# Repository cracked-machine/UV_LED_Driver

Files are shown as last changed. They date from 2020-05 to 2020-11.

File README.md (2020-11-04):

# UV LightBox

- Required Kicad Hardware library: https://github.com/cracked-machine/KicadLibrary
- Related SW project: https://github.com/cracked-machine/UV_LED_Driver_SW_STM32F051

This is a modular design that drives 4 panels of UV LEDS and 1 standard LED string.

<P>


</P>

- When the lightbox lid is open the standard LEDS are enabled. Their brightness can be adjusted using the rotary encoder control.
- When the lightbox lid is closed the UV LEDS are enabled.
- A timer will keep the UV LEDS enabled. When the timeout expires a buzzer will sound and the UV LEDS will be disabled. The timeout can be adjusted when using two buttons in steps of 10 seconds.
- A QVGA (2.2" 320x240) TFT LCD display shows the timer value.

- **OOTB operation runs on 5VDC. However, if higher voltage is required regulators U2 and U4 can be populated. These protect the LCD and Buzzer (JP3 and JP1 must be ON, JP2 and JP4 must be OFF)**

Module |Front |Back
:-----:|:-----:|:-----:
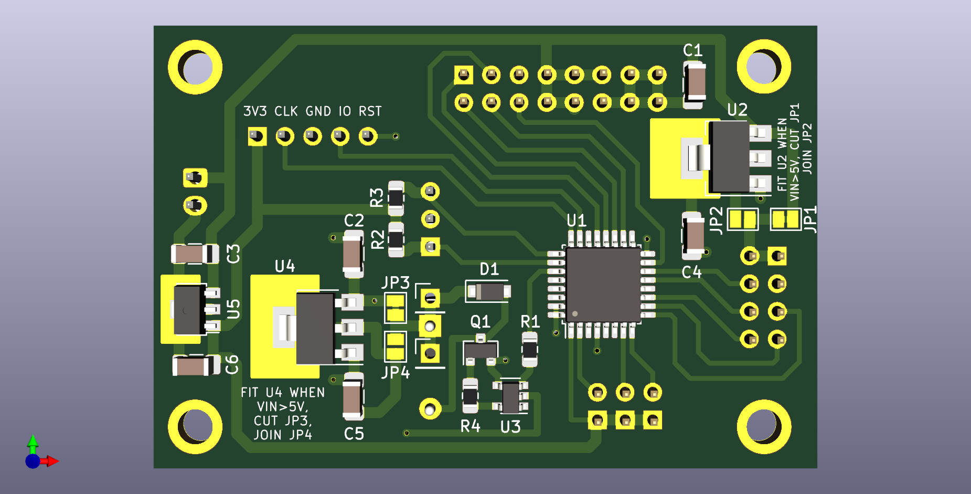
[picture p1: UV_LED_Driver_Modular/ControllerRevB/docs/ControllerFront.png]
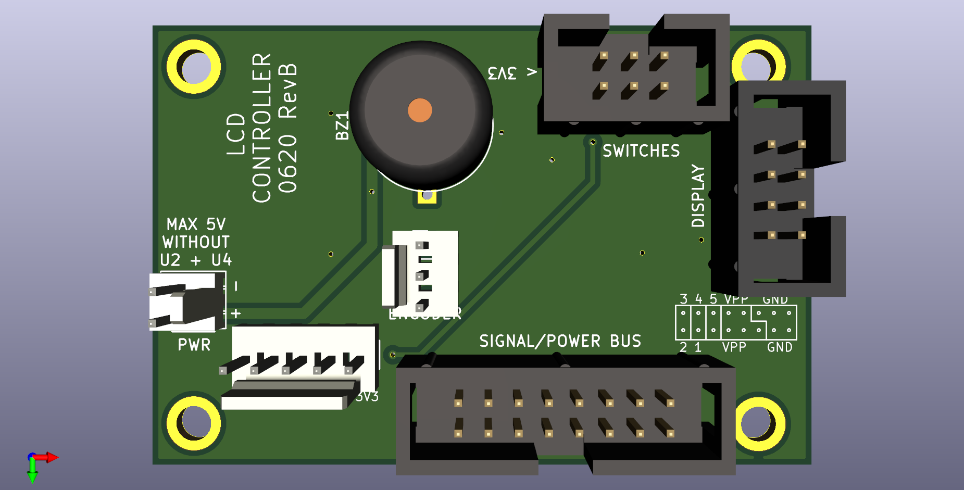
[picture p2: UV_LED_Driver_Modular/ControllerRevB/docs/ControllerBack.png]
Controller||
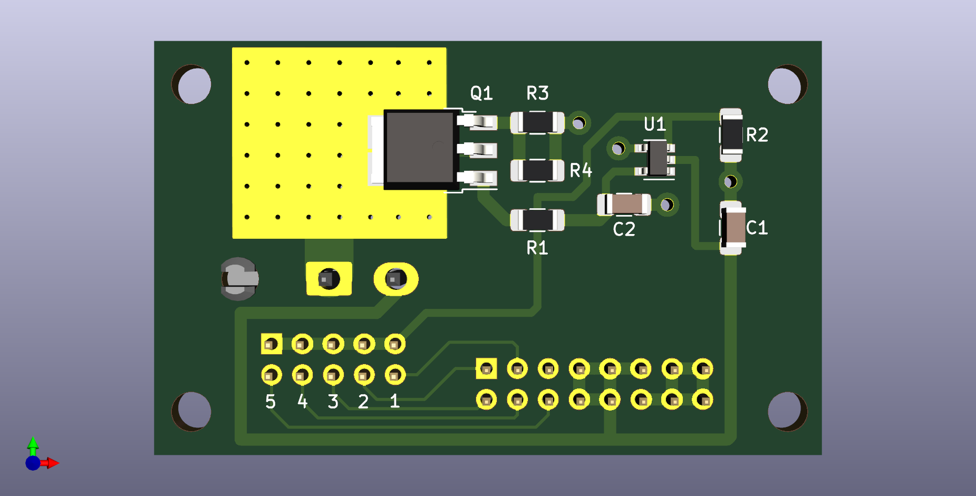
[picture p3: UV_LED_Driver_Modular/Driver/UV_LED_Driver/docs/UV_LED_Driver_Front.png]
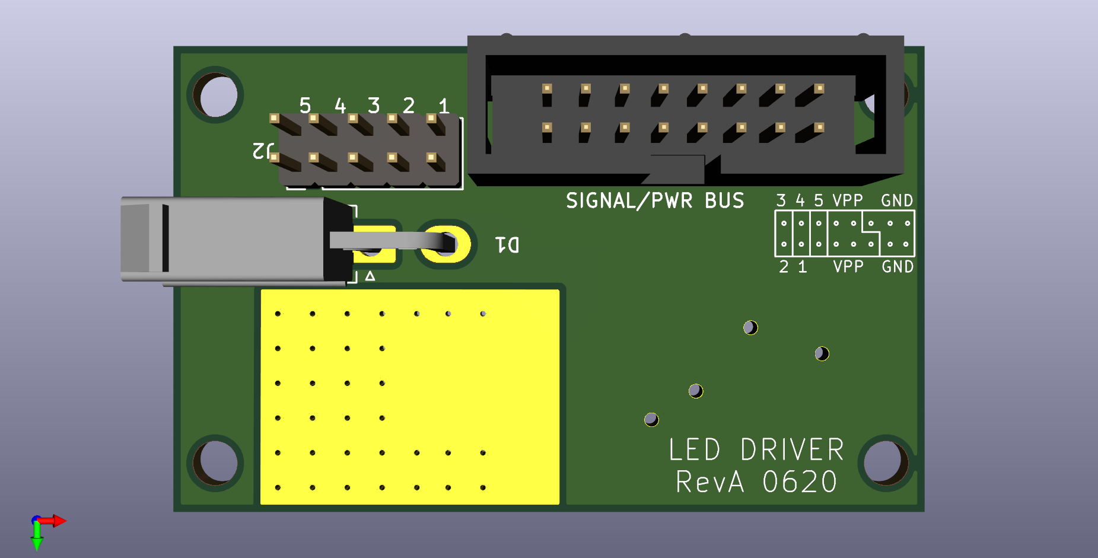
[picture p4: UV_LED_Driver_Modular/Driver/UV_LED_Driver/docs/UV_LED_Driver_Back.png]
Driver||

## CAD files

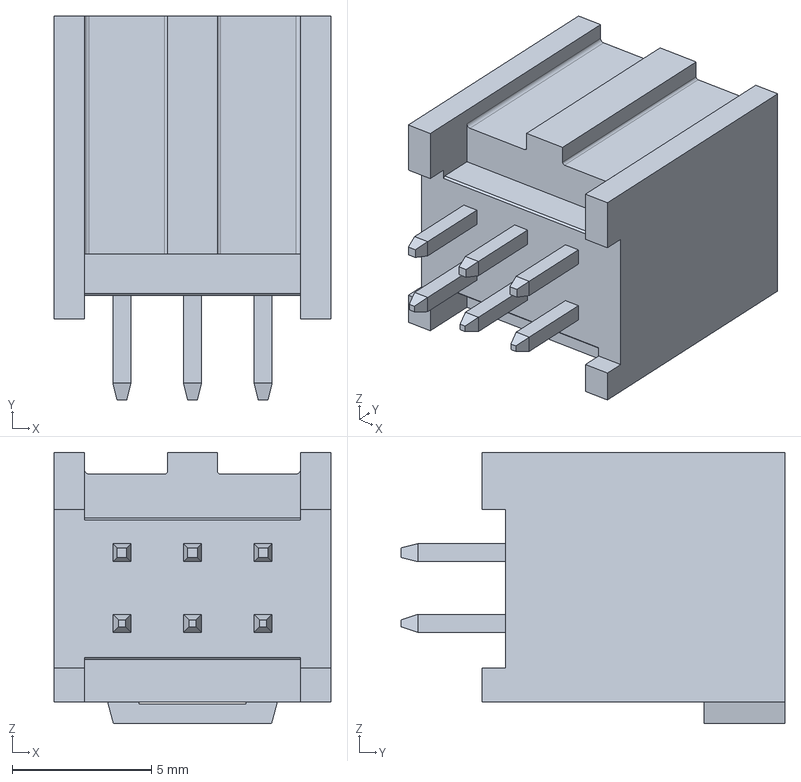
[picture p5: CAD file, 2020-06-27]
UV_LED_Driver_Modular/ControllerRevB/step/Molex_C-Grid_III_90130_6_Way_2_Row_Straight_PCB_Header_901301206.stp
9.96 x 13.8 x 9.75 mm

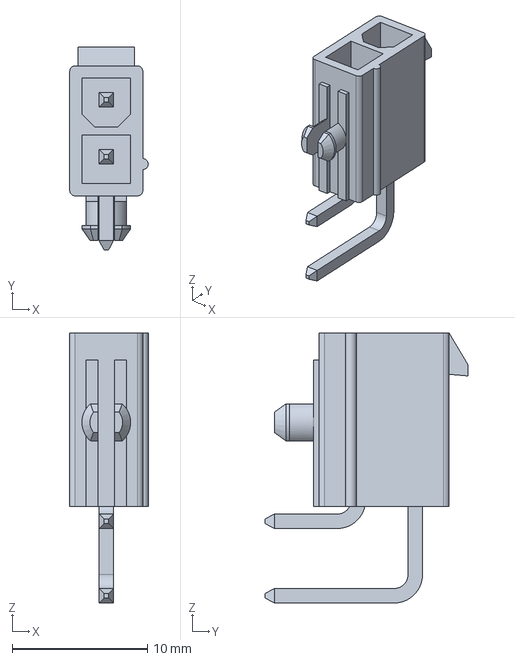
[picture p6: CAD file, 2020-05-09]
UV_LED_Driver_Modular/Driver/UV_LED_Driver/3D/39301020.stp
5.80 x 15.0 x 19.9 mm

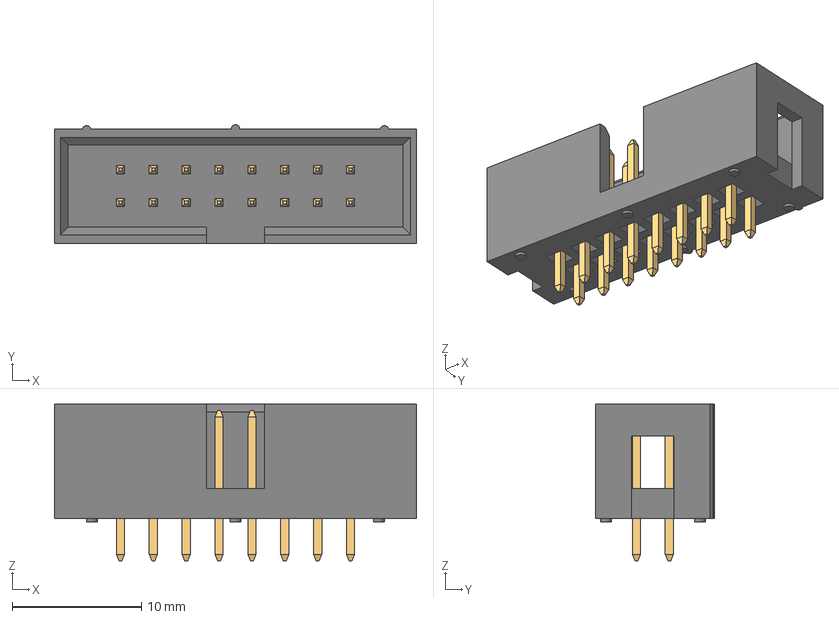
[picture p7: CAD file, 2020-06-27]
UV_LED_Driver_Modular/ControllerRevB/step/61201621621_Download_STP_61201621621_rev1.stp
28.0 x 9.18 x 12.1 mm
6120xx21621_PIN x 16

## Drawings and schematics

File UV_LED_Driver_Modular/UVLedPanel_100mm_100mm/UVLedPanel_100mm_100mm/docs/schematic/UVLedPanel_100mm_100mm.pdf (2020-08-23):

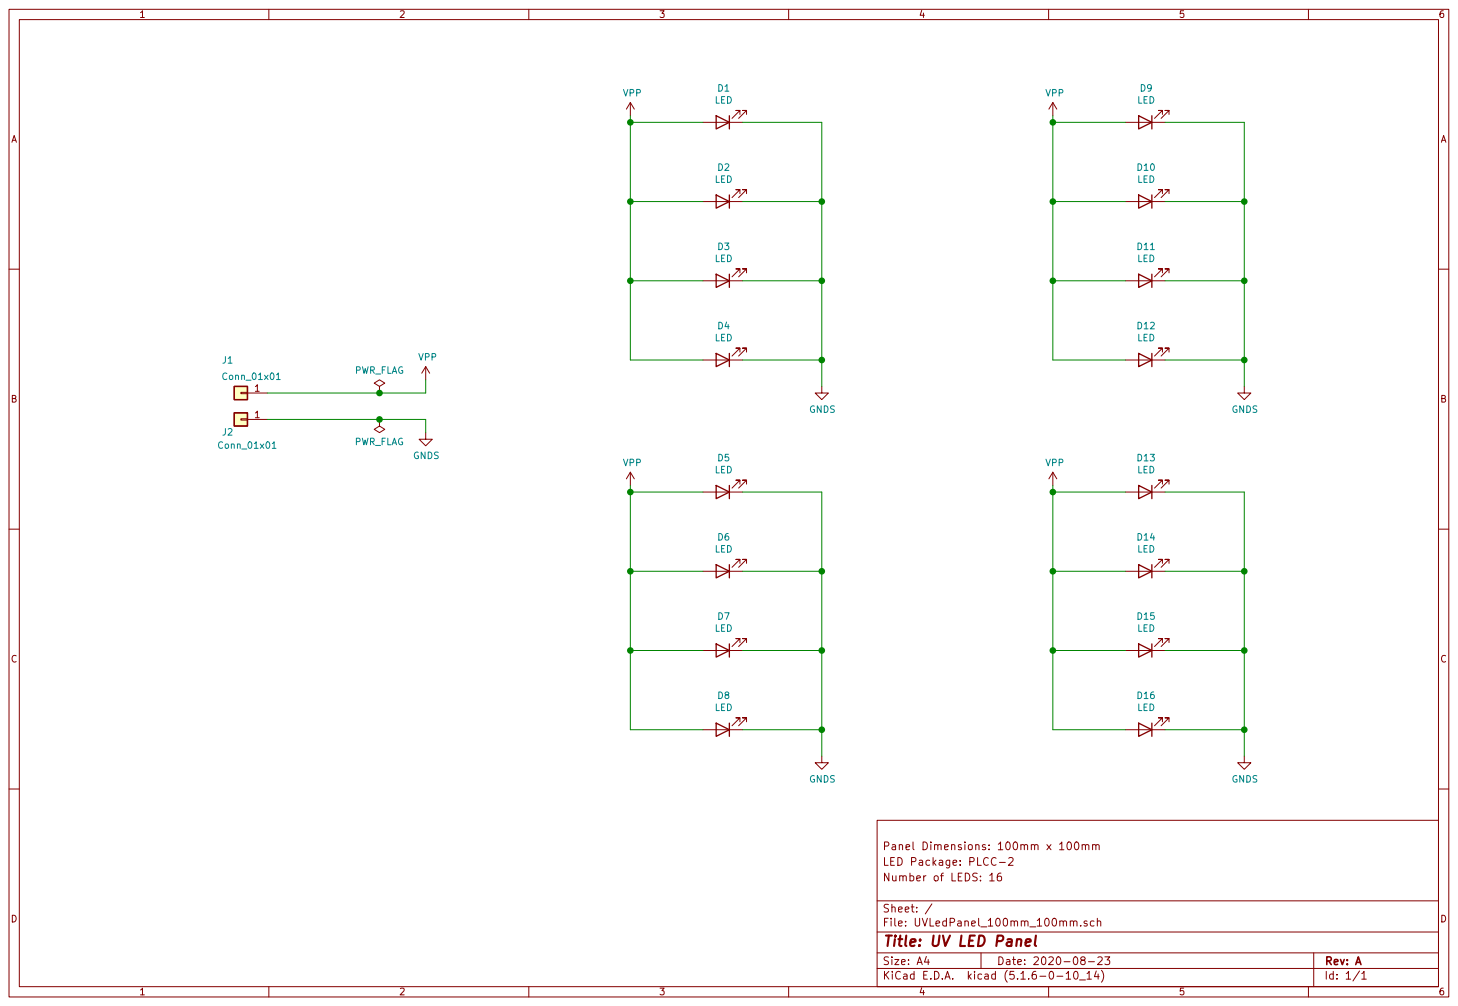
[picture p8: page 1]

LED Package: PLCC-2 Panel Dimensions: 100mm x 100mm

File: UVLedPanel_100mm_100mm.sch Sheet: / Number of LEDS: 16

Id: 1/1 Title: UV LED Panel

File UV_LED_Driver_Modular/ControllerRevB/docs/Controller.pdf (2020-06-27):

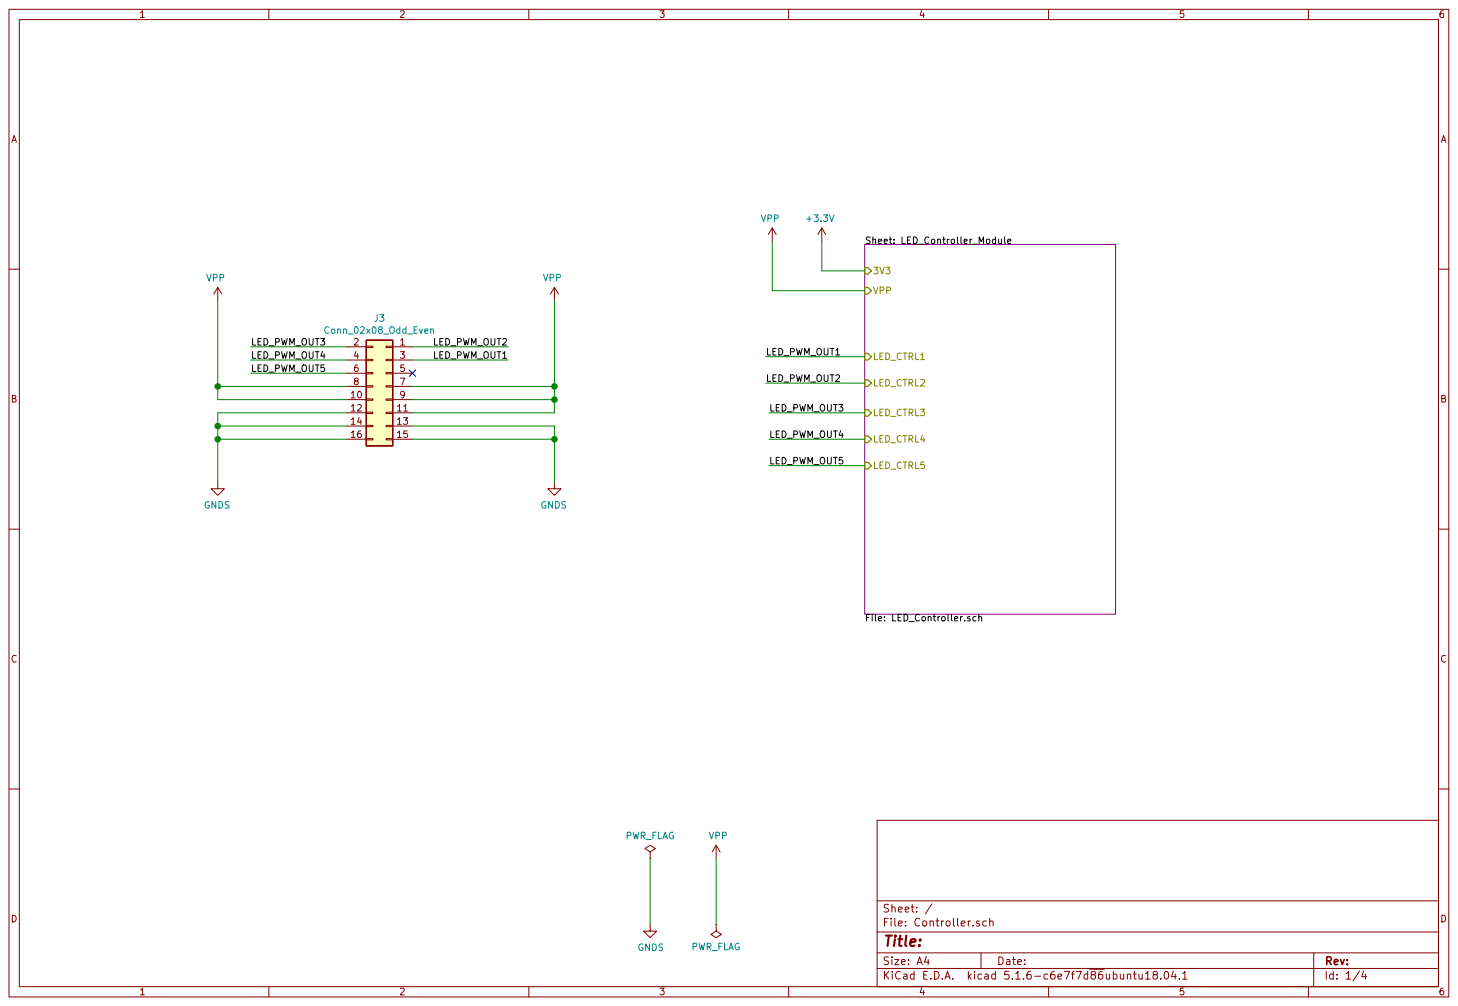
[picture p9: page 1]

14 | 13
16 | 15

Id: 1/4 Title: File: Controller.sch Sheet: /

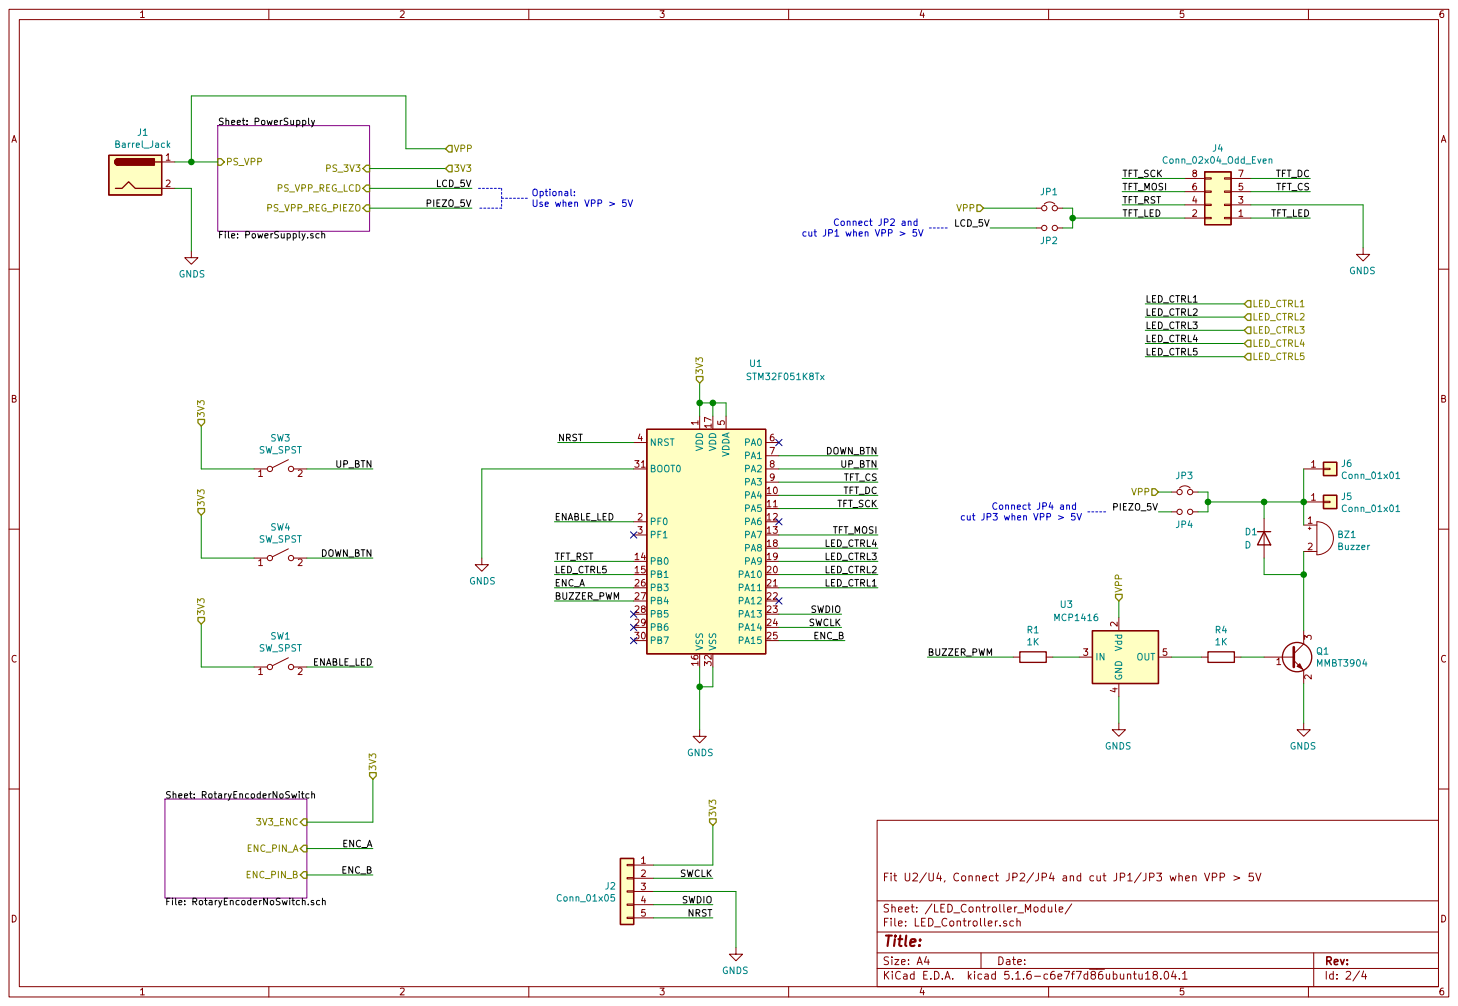
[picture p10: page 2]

Fit U2/U4, Connect JP2/JP4 and cut JP1/JP3 when VPP > 5V

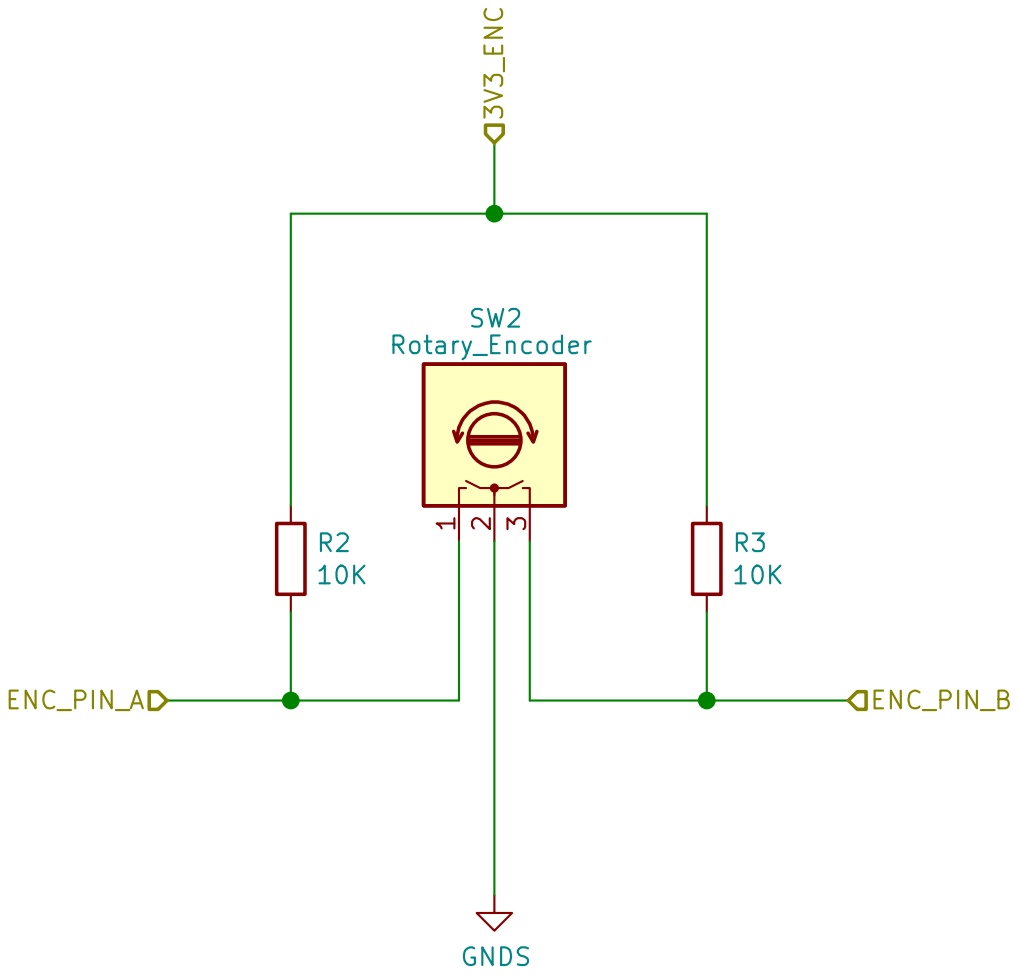
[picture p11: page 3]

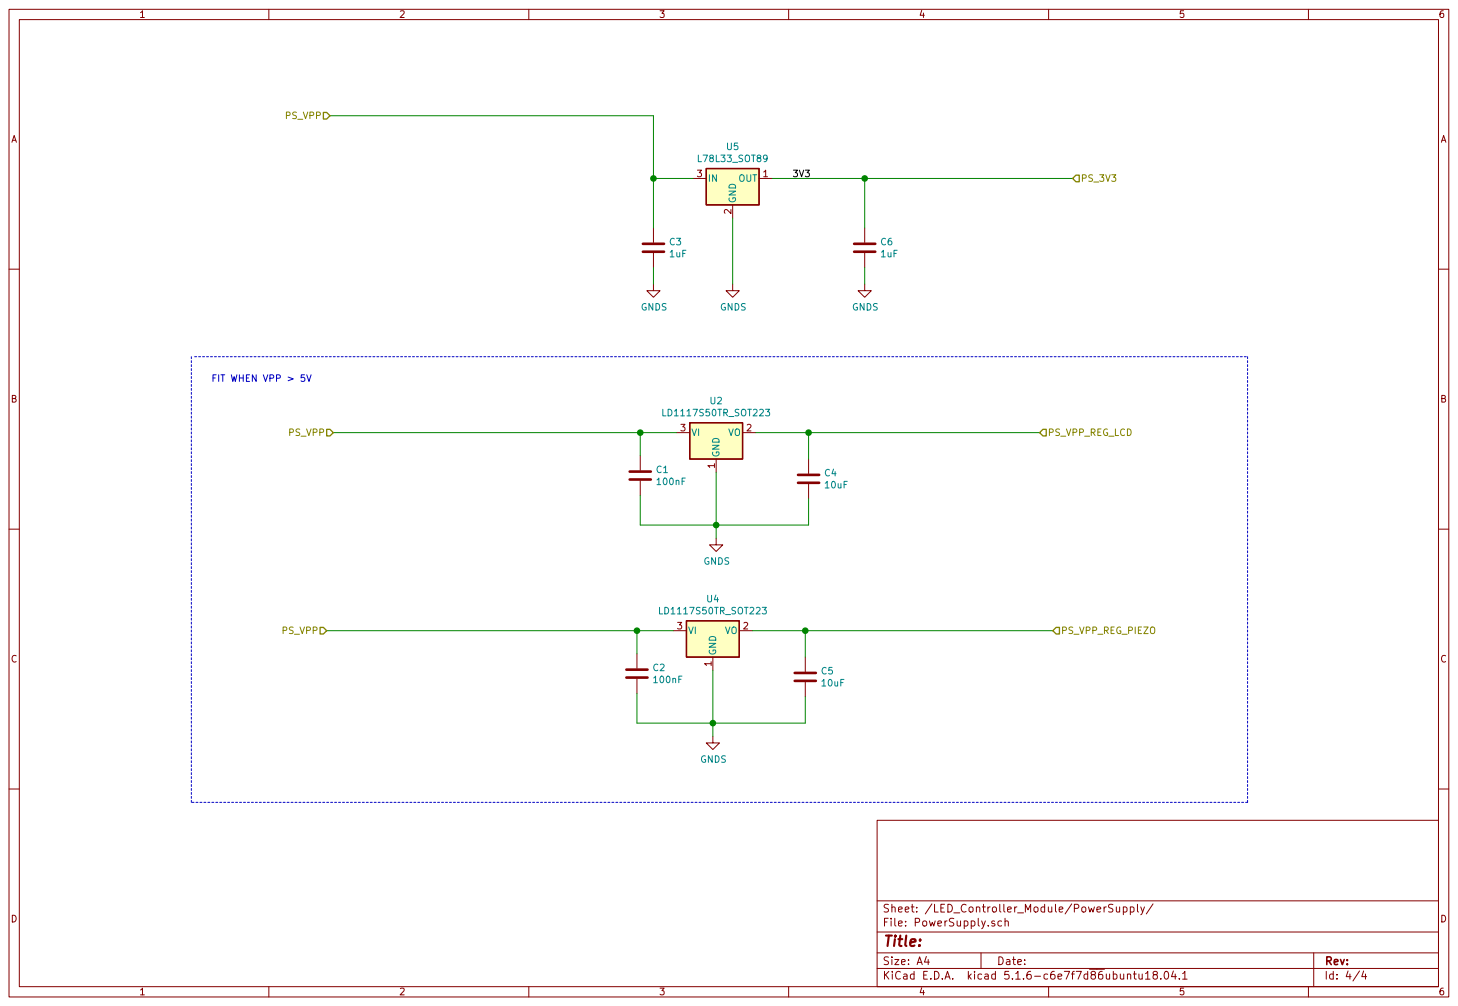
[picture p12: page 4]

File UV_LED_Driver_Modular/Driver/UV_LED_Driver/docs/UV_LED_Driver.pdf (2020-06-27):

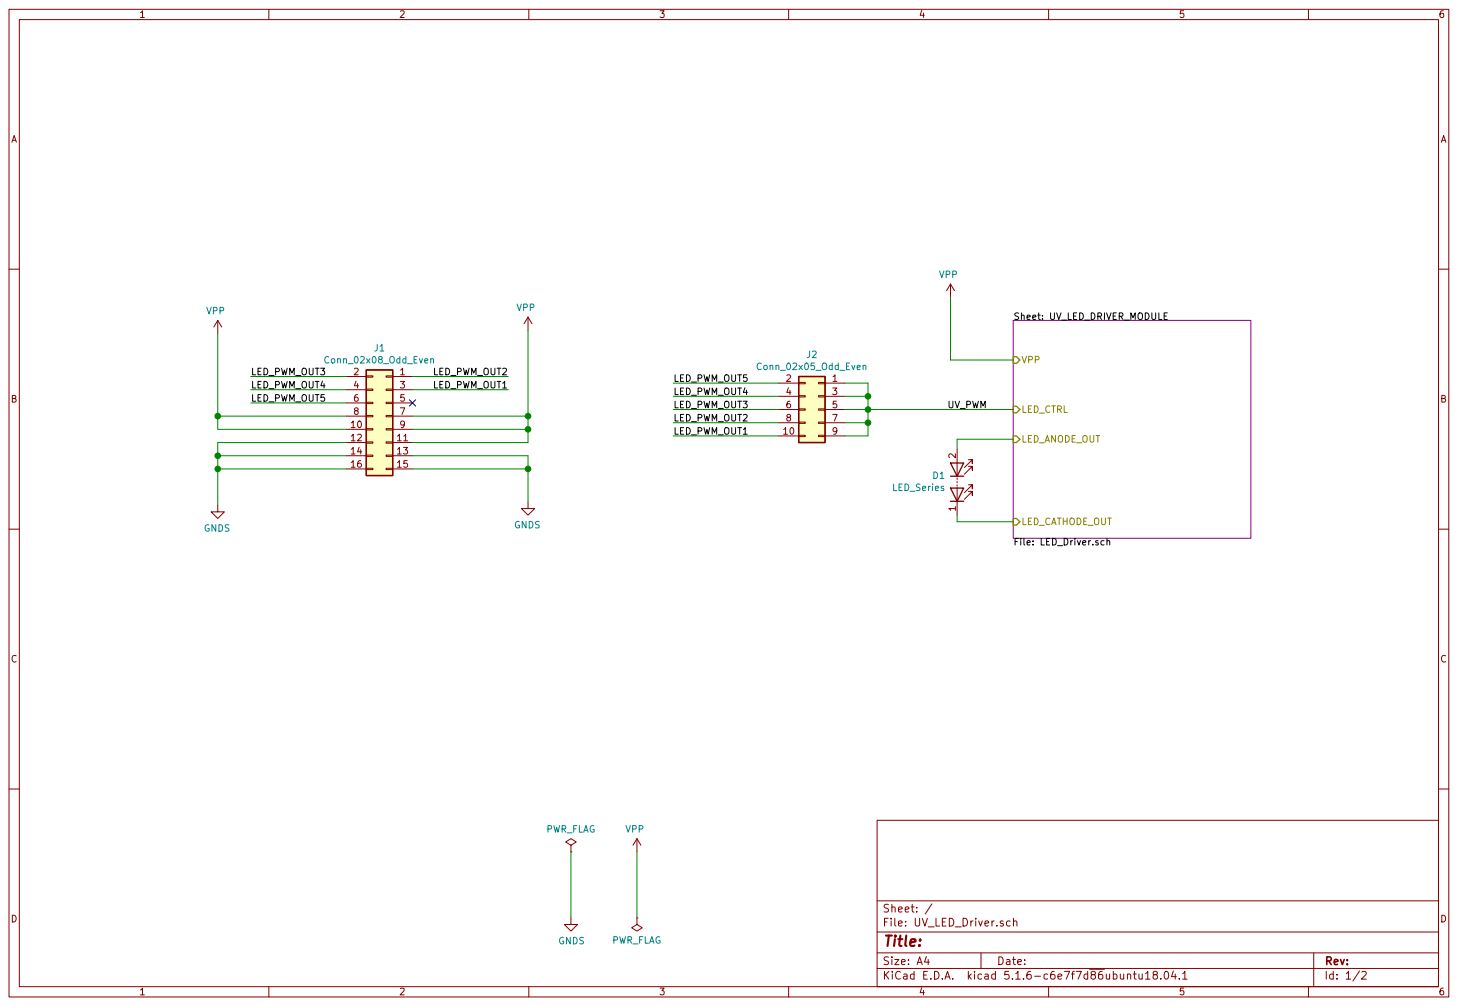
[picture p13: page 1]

14 | 13
16 | 15

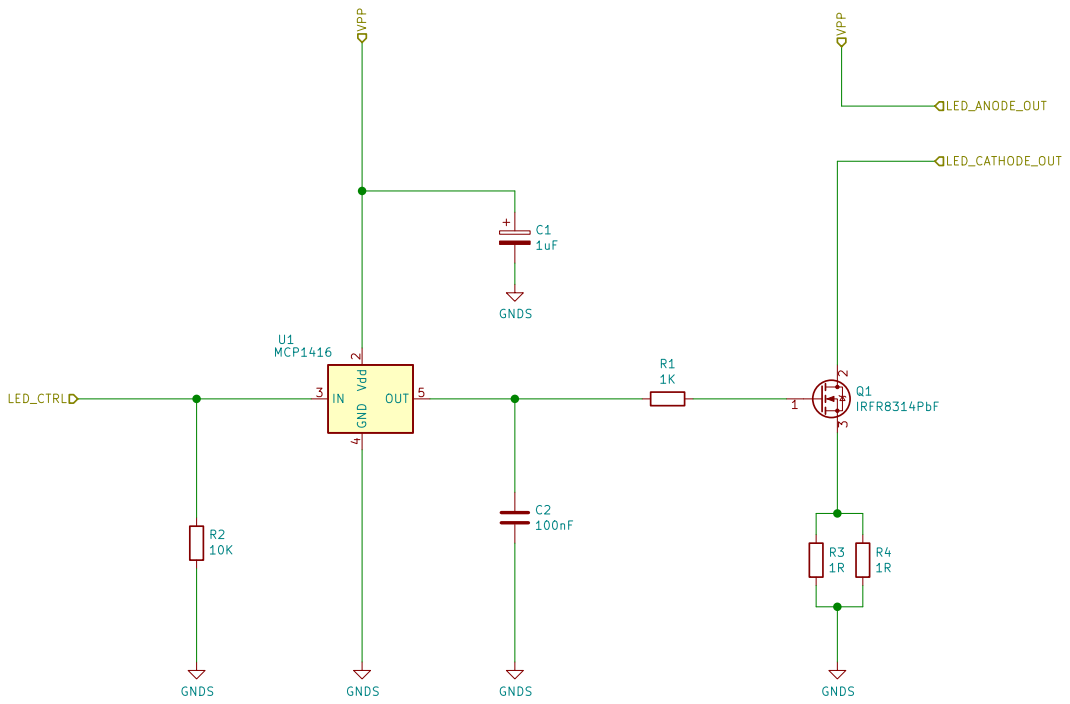
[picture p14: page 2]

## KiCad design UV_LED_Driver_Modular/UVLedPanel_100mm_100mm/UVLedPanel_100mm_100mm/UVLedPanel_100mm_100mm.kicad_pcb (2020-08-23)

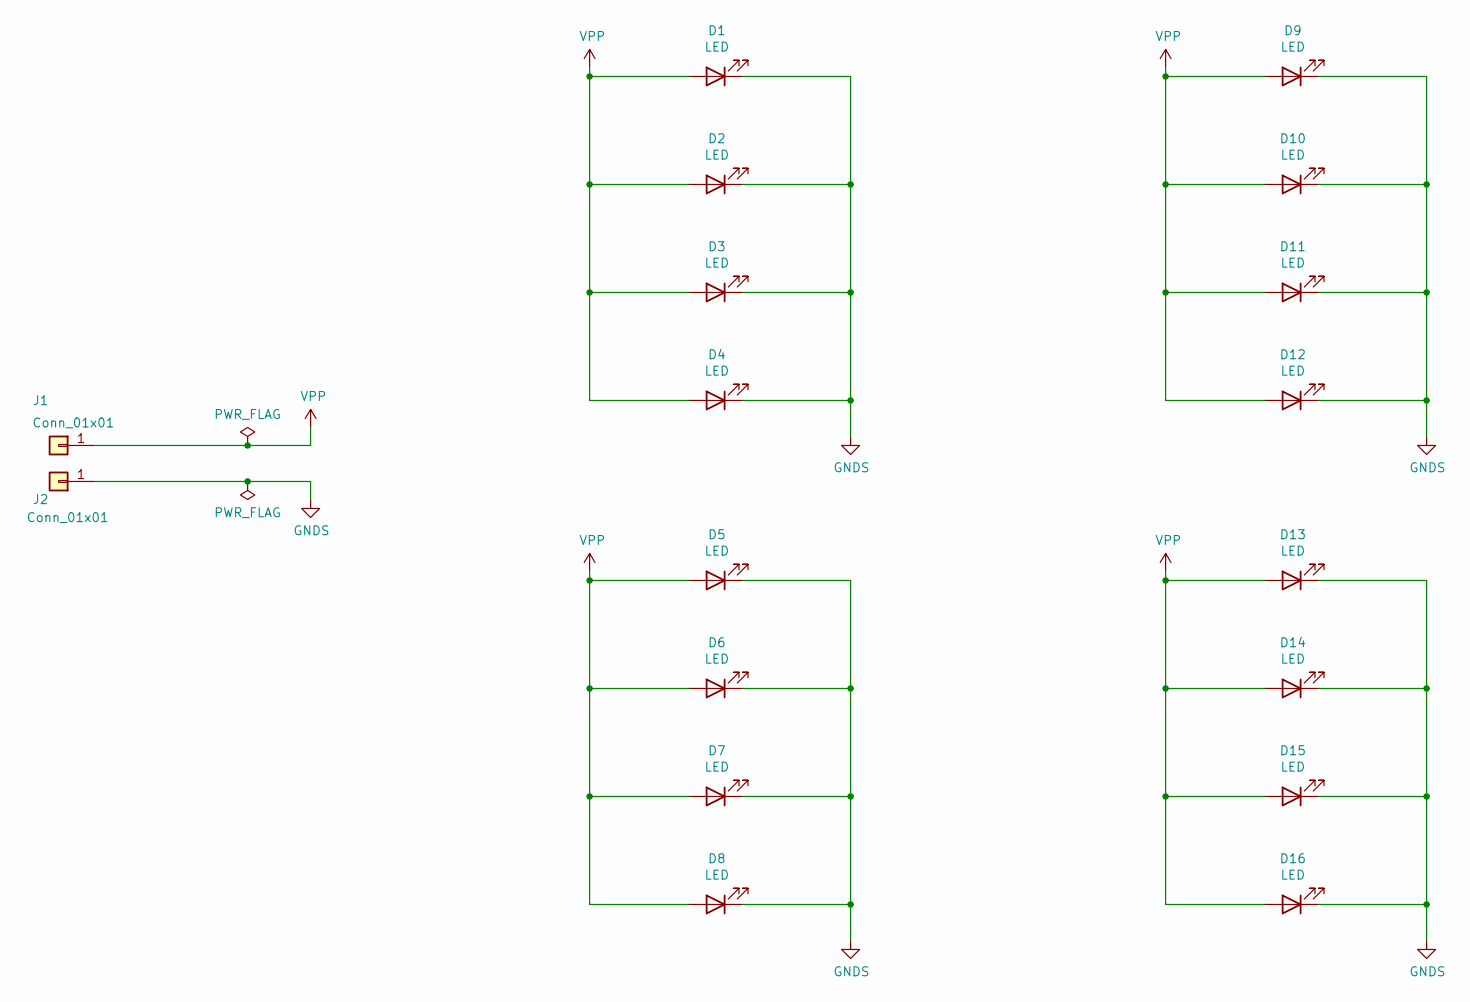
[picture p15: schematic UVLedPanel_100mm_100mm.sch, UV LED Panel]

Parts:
D1, D2, D3, D4, D5, D6, D7, D8, D9, D10, D11, D12, D13, D14, D15, D16: LED; LED_PLCC-2
J1, J2: Conn_01x01; TestPoint_Pad_4.0x4.0mm

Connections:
GNDS: D1.1 (K), D2.1 (K), D3.1 (K), D4.1 (K), D5.1 (K), D6.1 (K), D7.1 (K), D8.1 (K), D9.1 (K), D10.1 (K), D11.1 (K), D12.1 (K), D13.1 (K), D14.1 (K), D15.1 (K), D16.1 (K), J2.1
VPP: D1.2 (A), D2.2 (A), D3.2 (A), D4.2 (A), D5.2 (A), D6.2 (A), D7.2 (A), D8.2 (A), D9.2 (A), D10.2 (A), D11.2 (A), D12.2 (A), D13.2 (A), D14.2 (A), D15.2 (A), D16.2 (A), J1.1

Board: 2 copper layers, 18 parts (0 on the bottom side), 2 nets, no tracks yet.

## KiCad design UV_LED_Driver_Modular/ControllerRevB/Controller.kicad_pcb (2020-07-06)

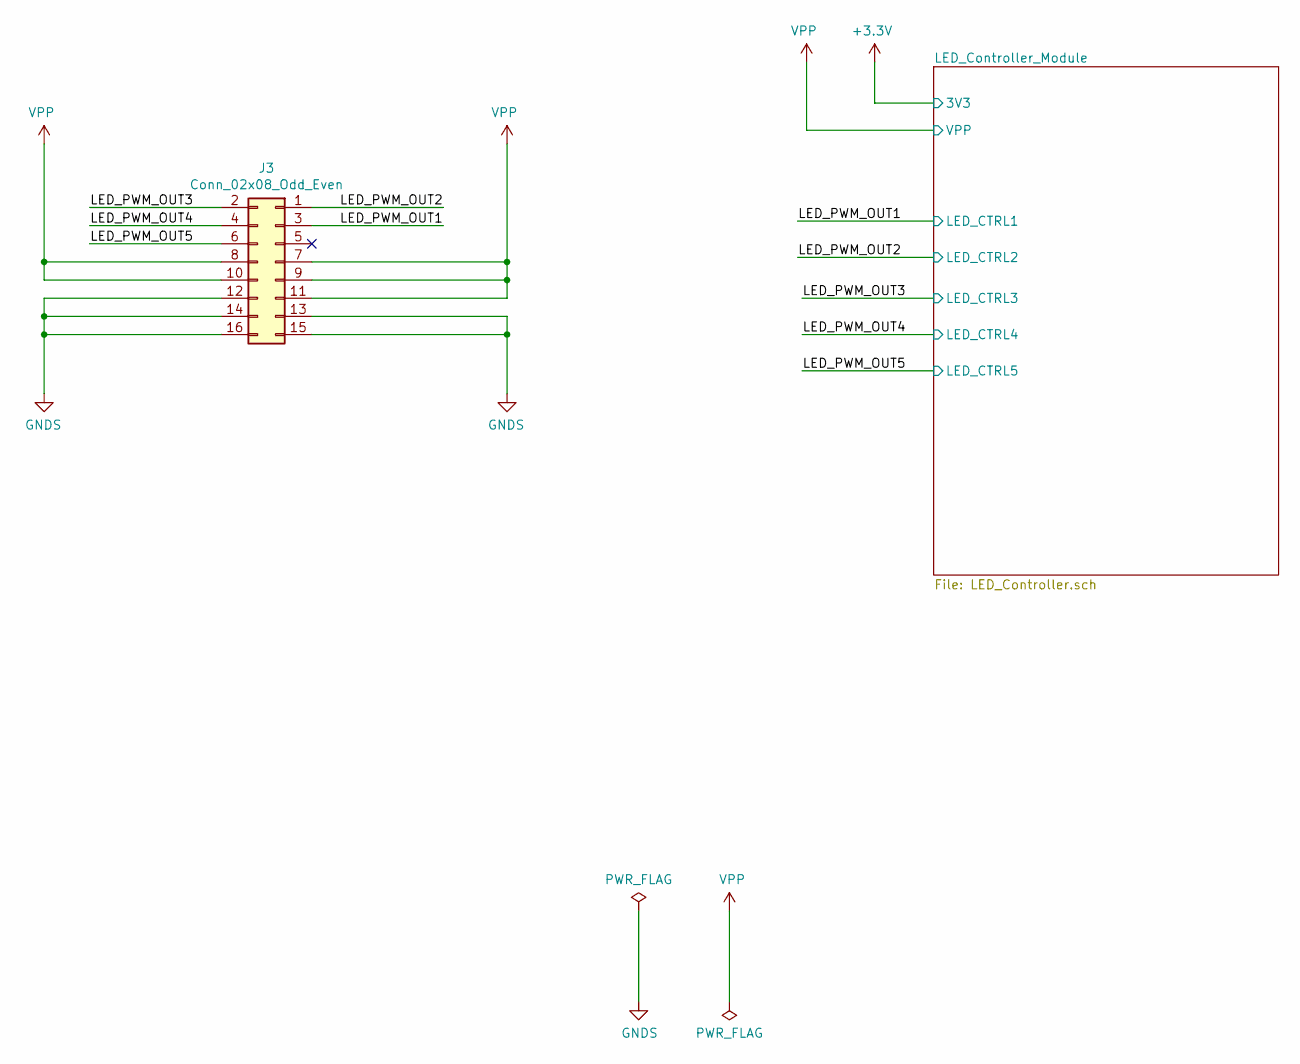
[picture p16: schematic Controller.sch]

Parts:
J3: Conn_02x08_Odd_Even; PinHeader_2x08_P2.54mm_Vertical

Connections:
/LED_PWM_OUT1: J3.3; also elsewhere on the board
/LED_PWM_OUT2: J3.1; also elsewhere on the board
/LED_PWM_OUT3: J3.2; also elsewhere on the board
/LED_PWM_OUT4: J3.4; also elsewhere on the board
/LED_PWM_OUT5: J3.6; also elsewhere on the board
GNDS: J3.12, J3.13, J3.14, J3.15, J3.16; also elsewhere on the board
VPP: J3.7, J3.8, J3.9, J3.10, J3.11; also elsewhere on the board

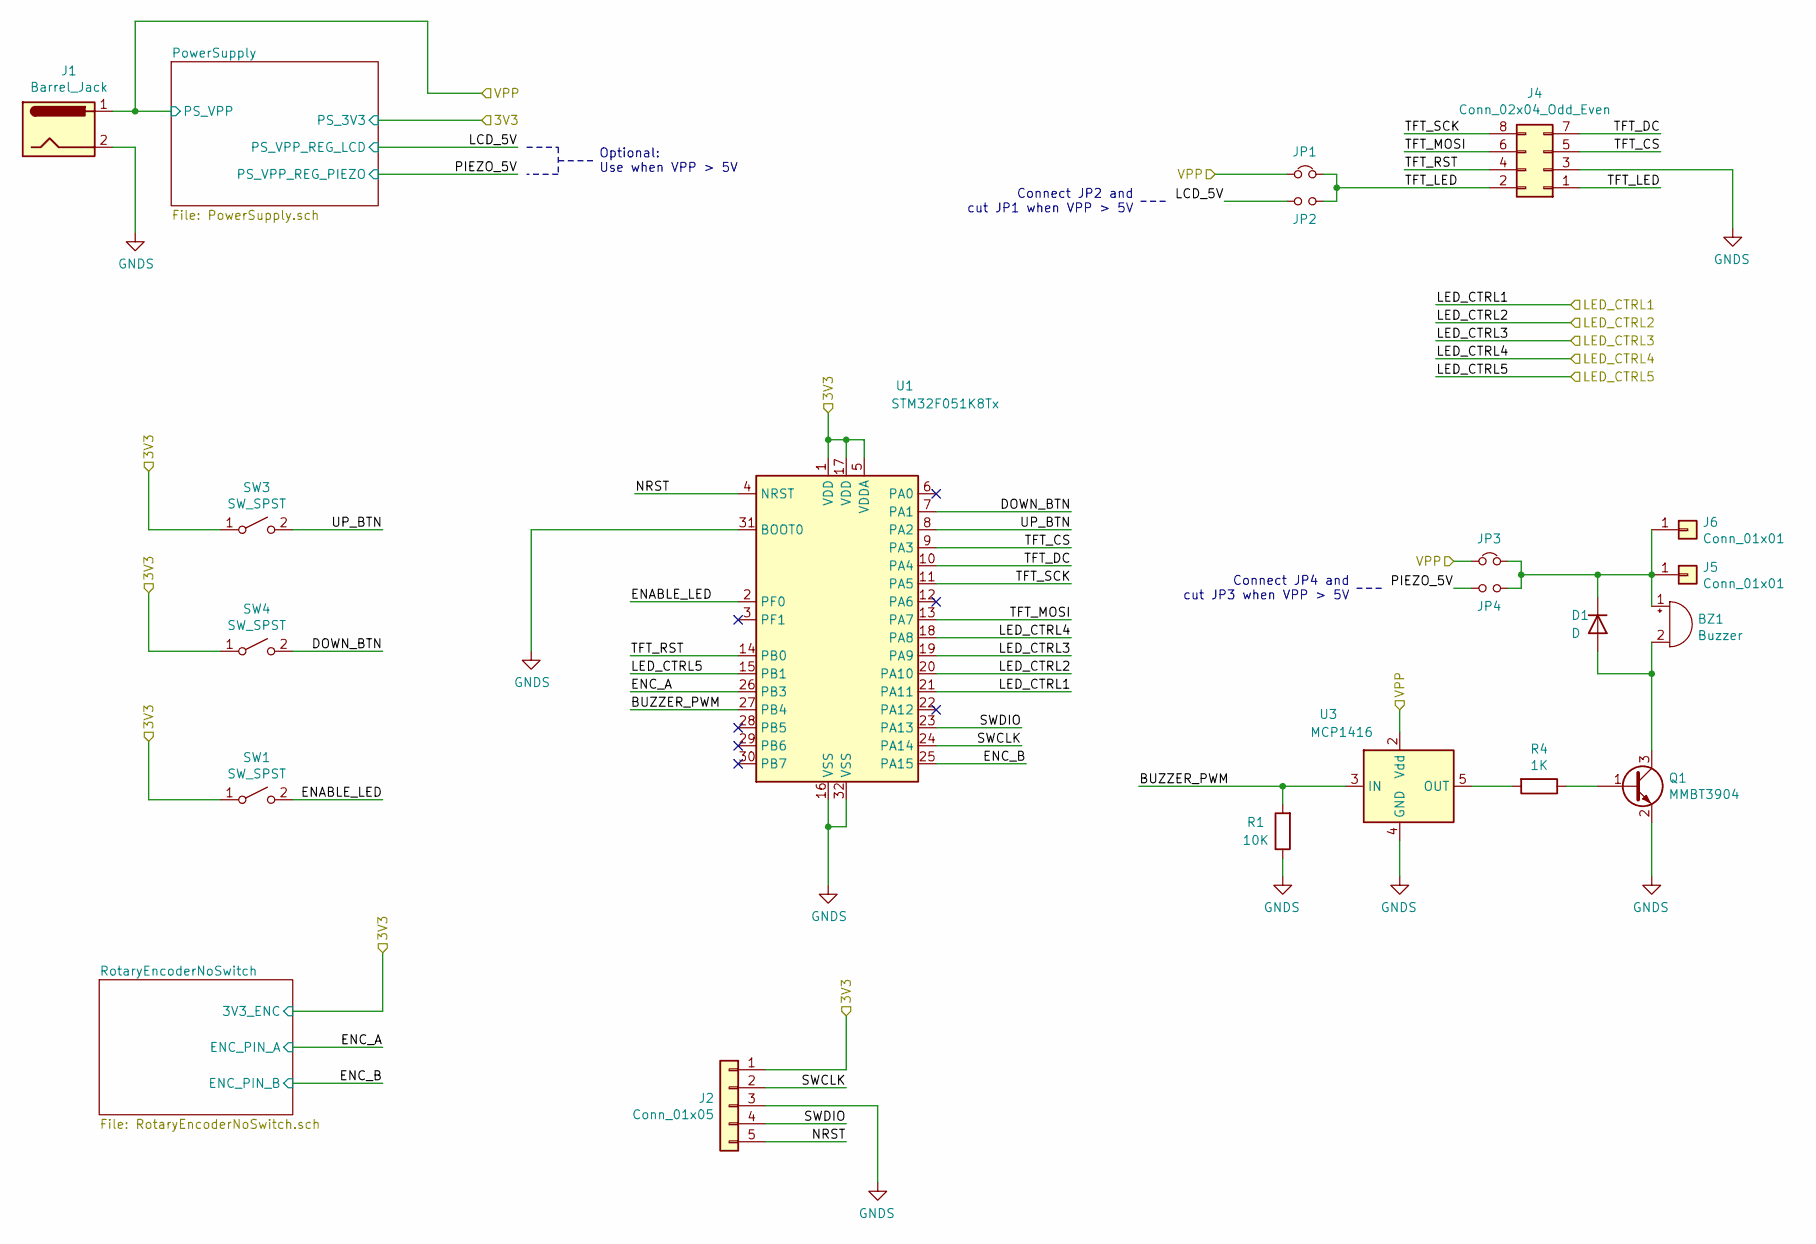
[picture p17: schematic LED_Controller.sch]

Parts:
BZ1: Buzzer; Buzzer_12x9.5RM7.6
D1: D; D_SOD-123F
J1: Barrel_Jack; Molex_KK-254_AE-6410-02A_1x02_P2.54mm_Vertical
J2: Conn_01x05; PinHeader_1x05_P2.54mm_Vertical
J4: Conn_02x04_Odd_Even; PinHeader_2x04_P2.54mm_Vertical
J5, J6: Conn_01x01; PinHeader_1x01_P2.54mm_Vertical
JP1, JP3: Jumper_NC_Small; SolderJumper-2_P1.3mm_Bridged_Pad1.0x1.5mm
JP2, JP4: Jumper_NO_Small; SolderJumper-2_P1.3mm_Open_Pad1.0x1.5mm
Q1: MMBT3904; SOT-23
R1: 10K; R_0805_2012Metric_Pad1.15x1.40mm_HandSolder
R4: 1K; R_0805_2012Metric_Pad1.15x1.40mm_HandSolder
SW1, SW3, SW4: SW_SPST; PinHeader_1x02_P2.54mm_Vertical
U1: STM32F051K8Tx; LQFP-32_7x7mm_P0.8mm
U3: MCP1416; SOT-23-5

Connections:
+3V3: J2.1, SW1.1 (A), SW3.1 (A), SW4.1 (A), U1.1 (VDD), U1.5 (VDDA), U1.17 (VDD); also elsewhere on the board
/LED_Controller_Module/BUZZER_PWM: R1.2, U1.27 (PB4), U3.3 (IN)
/LED_Controller_Module/DOWN_BTN: SW4.2 (B), U1.7 (PA1)
/LED_Controller_Module/ENABLE_LED: SW1.2 (B), U1.2 (PF0)
/LED_Controller_Module/ENC_A: U1.26 (PB3); also elsewhere on the board
/LED_Controller_Module/ENC_B: U1.25 (PA15); also elsewhere on the board
/LED_Controller_Module/LCD_5V: JP2.1; also elsewhere on the board
/LED_Controller_Module/NRST: J2.5, U1.4 (NRST)
/LED_Controller_Module/PIEZO_5V: JP4.1; also elsewhere on the board
/LED_Controller_Module/SWCLK: J2.2, U1.24 (PA14)
/LED_Controller_Module/SWDIO: J2.4, U1.23 (PA13)
/LED_Controller_Module/TFT_CS: J4.5, U1.9 (PA3)
/LED_Controller_Module/TFT_DC: J4.7, U1.10 (PA4)
/LED_Controller_Module/TFT_LED: J4.1, J4.2, JP1.2, JP2.2
/LED_Controller_Module/TFT_MOSI: J4.6, U1.13 (PA7)
/LED_Controller_Module/TFT_RST: J4.4, U1.14 (PB0)
/LED_Controller_Module/TFT_SCK: J4.8, U1.11 (PA5)
/LED_Controller_Module/UP_BTN: SW3.2 (B), U1.8 (PA2)
/LED_PWM_OUT1: U1.21 (PA11); also elsewhere on the board
/LED_PWM_OUT2: U1.20 (PA10); also elsewhere on the board
/LED_PWM_OUT3: U1.19 (PA9); also elsewhere on the board
/LED_PWM_OUT4: U1.18 (PA8); also elsewhere on the board
/LED_PWM_OUT5: U1.15 (PB1); also elsewhere on the board
GNDS: J1.2, J2.3, J4.3, Q1.2 (E), R1.1, U1.16 (VSS), U1.31 (BOOT0), U1.32 (VSS), U3.4 (GND); also elsewhere on the board
unnamed: BZ1.1 (-), D1.1 (K), J5.1, J6.1, JP3.2, JP4.2
unnamed: BZ1.2 (+), D1.2 (A), Q1.3 (C)
unnamed: Q1.1 (B), R4.1
unnamed: R4.2, U3.5 (OUT)
VPP: J1.1, JP1.1, JP3.1, U3.2 (Vdd); also elsewhere on the board

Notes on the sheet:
Optional: Use when VPP > 5V
Connect JP2 and cut JP1 when VPP > 5V
Connect JP4 and cut JP3 when VPP > 5V

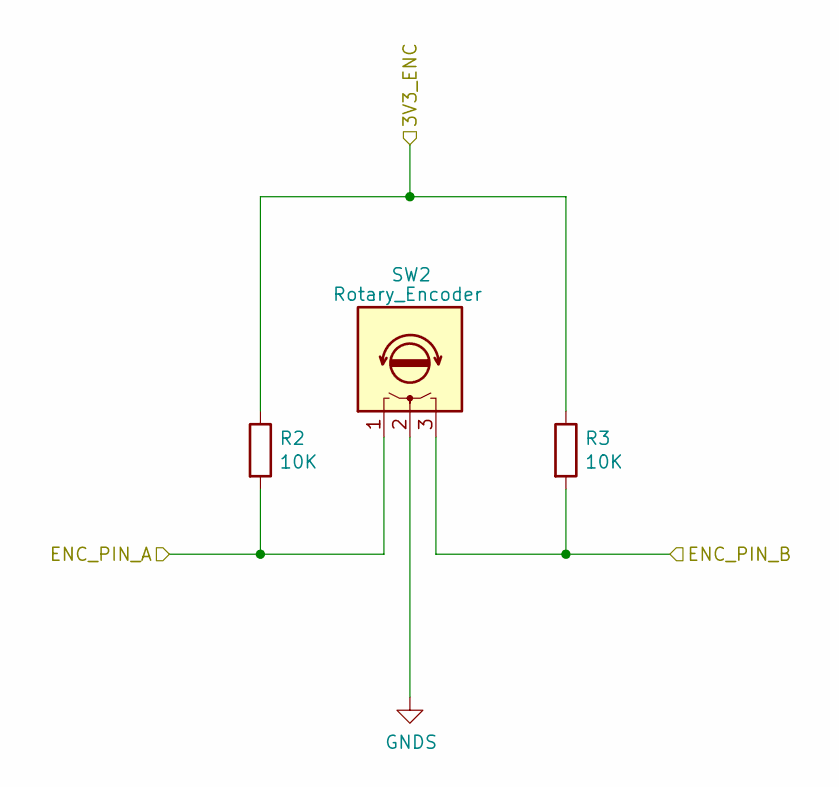
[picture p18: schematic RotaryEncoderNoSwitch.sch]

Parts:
R2, R3: 10K; R_0805_2012Metric_Pad1.15x1.40mm_HandSolder
SW2: Rotary_Encoder; PinHeader_1x03_P2.54mm_Vertical

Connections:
+3V3: R2.1, R3.1; also elsewhere on the board
/LED_Controller_Module/ENC_A: R2.2, SW2.1 (A); also elsewhere on the board
/LED_Controller_Module/ENC_B: R3.2, SW2.3 (B); also elsewhere on the board
GNDS: SW2.2 (C); also elsewhere on the board

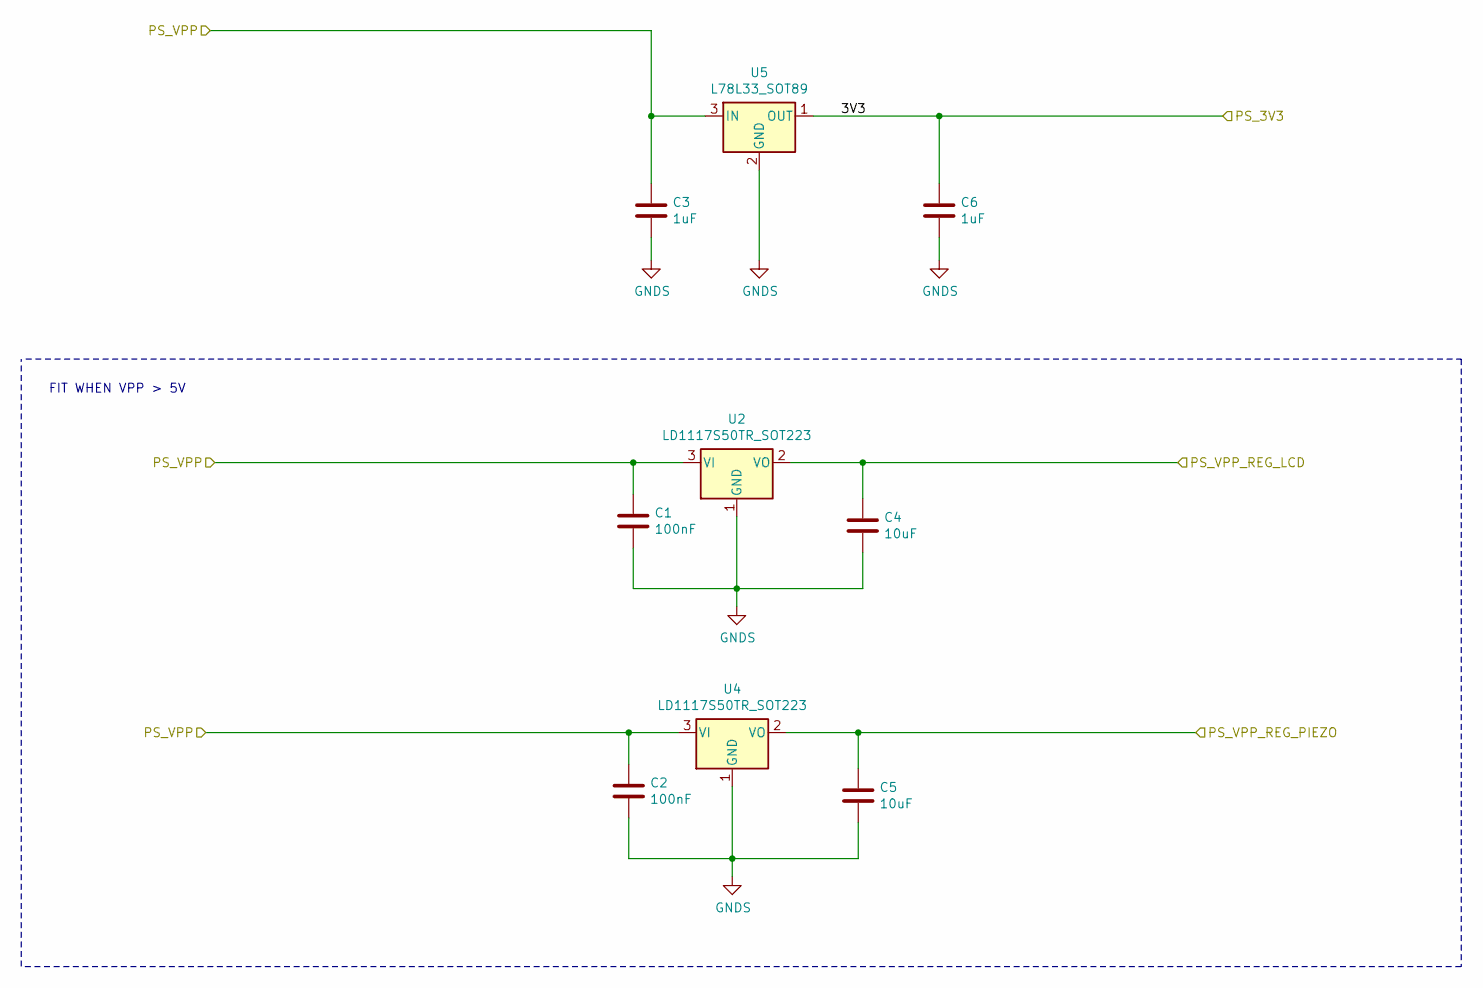
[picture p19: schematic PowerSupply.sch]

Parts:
C1, C2: 100nF; C_1206_3216Metric_Pad1.42x1.75mm_HandSolder
C3, C6: 1uF; C_1206_3216Metric_Pad1.42x1.75mm_HandSolder
C4, C5: 10uF; C_1206_3216Metric_Pad1.42x1.75mm_HandSolder
U2, U4: LD1117S50TR_SOT223; SOT-223-3_TabPin2
U5: L78L33_SOT89; SOT-89-3

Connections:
+3V3: C6.1, U5.1 (OUT); also elsewhere on the board
/LED_Controller_Module/LCD_5V: C4.1, U2.2 (VO); also elsewhere on the board
/LED_Controller_Module/PIEZO_5V: C5.1, U4.2 (VO); also elsewhere on the board
GNDS: C1.2, C2.2, C3.2, C4.2, C5.2, C6.2, U2.1 (GND), U4.1 (GND), U5.2 (GND); also elsewhere on the board
VPP: C1.1, C2.1, C3.1, U2.3 (VI), U4.3 (VI), U5.3 (IN); also elsewhere on the board

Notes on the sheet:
FIT WHEN VPP > 5V

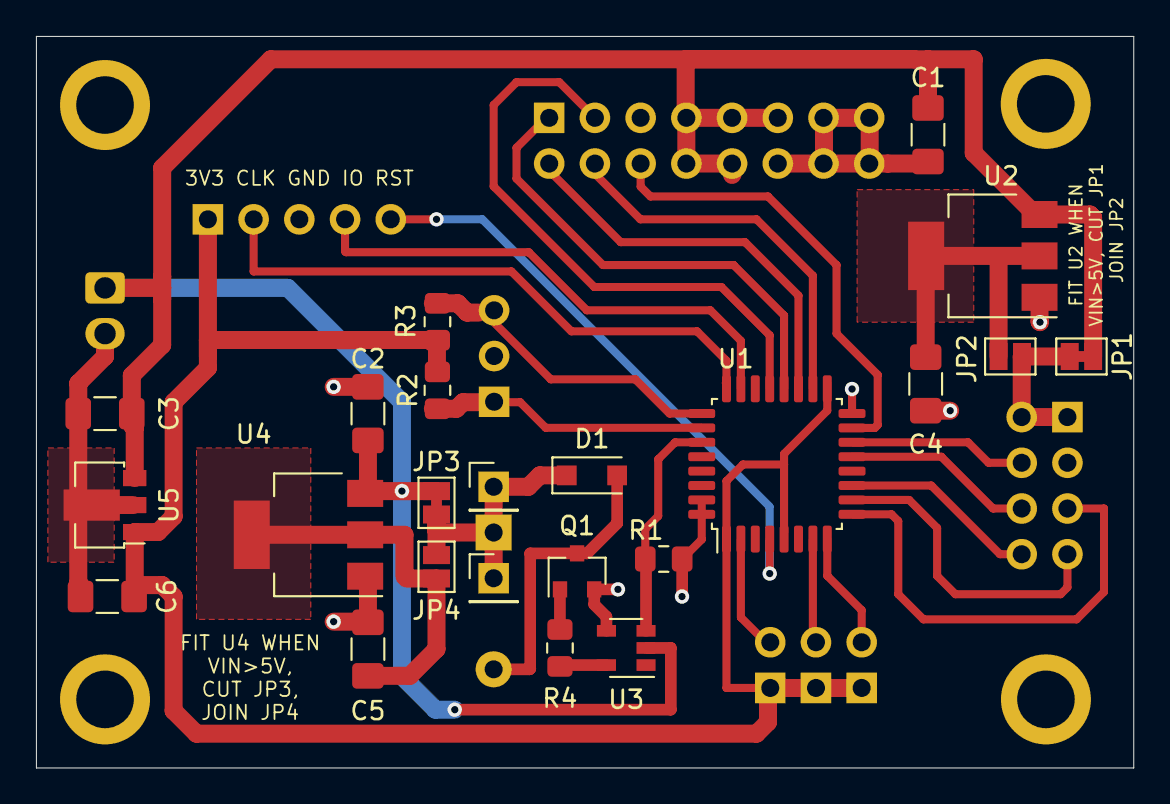
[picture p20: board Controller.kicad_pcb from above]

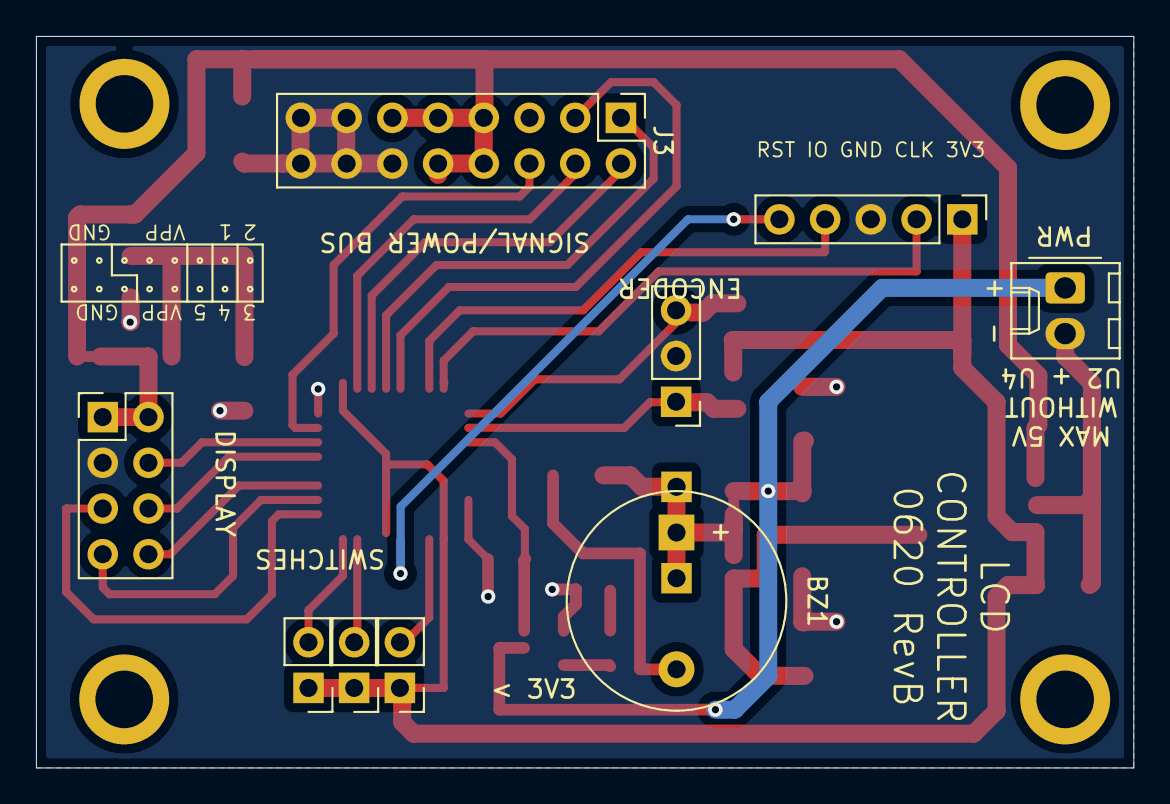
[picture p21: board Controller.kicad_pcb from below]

Board: 2 copper layers, 61.0 x 40.6 mm, 32 parts (9 on the bottom side), 29 nets.

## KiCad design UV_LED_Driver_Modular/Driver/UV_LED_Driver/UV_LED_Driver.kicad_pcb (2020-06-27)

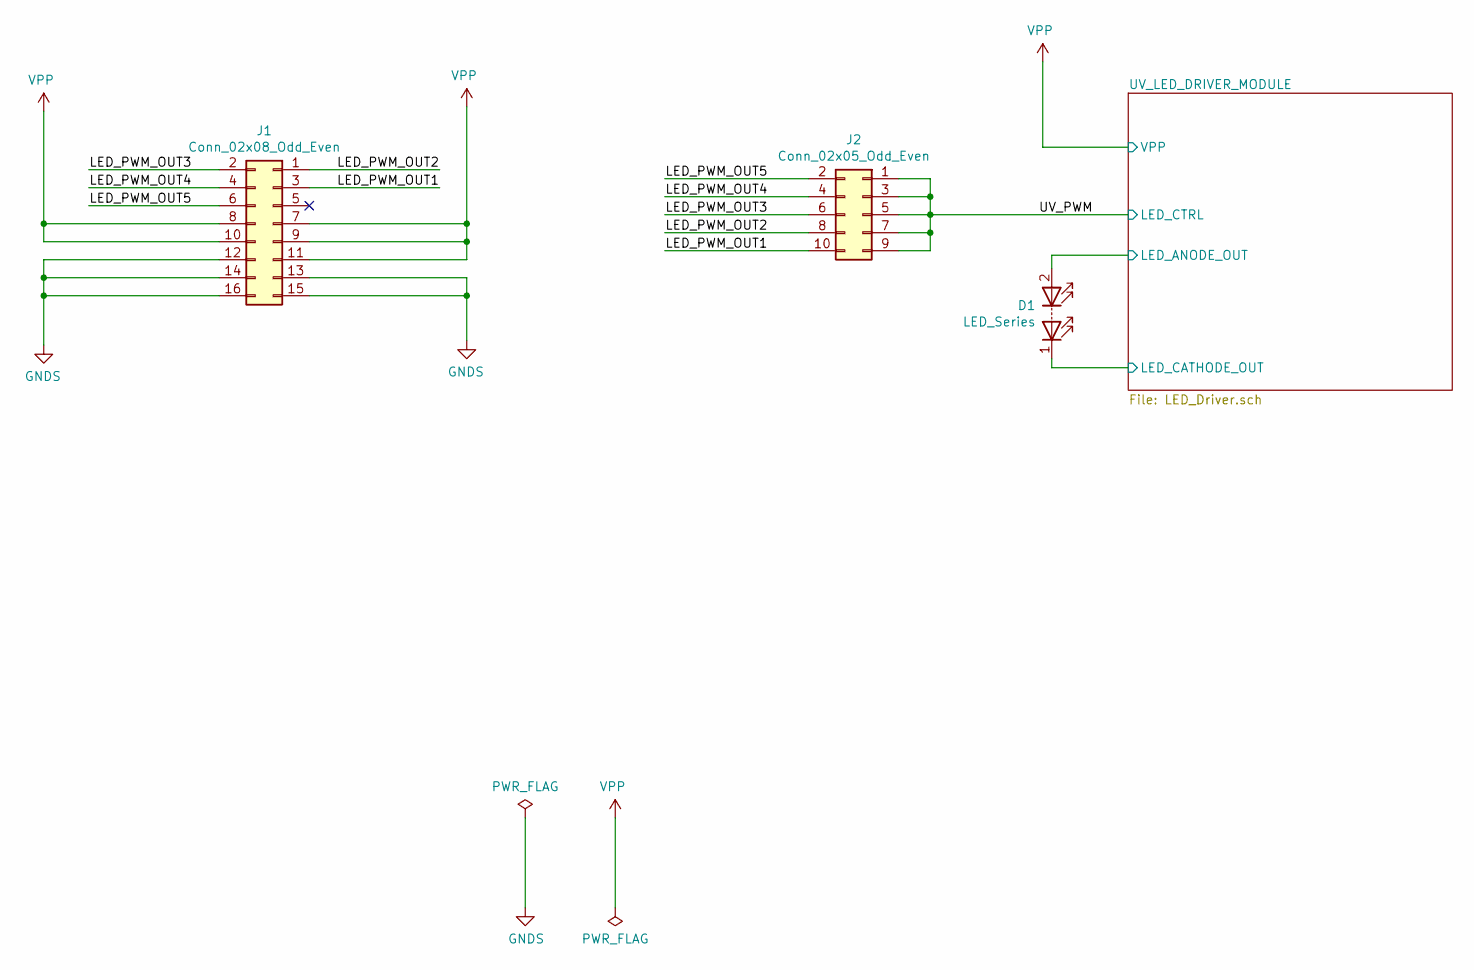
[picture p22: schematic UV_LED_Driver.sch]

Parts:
D1: LED_Series; Molex_Mini-Fit_Jr_5569-02A2_2x01_P4.20mm_Horizontal
J1: Conn_02x08_Odd_Even; PinHeader_2x08_P2.54mm_Vertical
J2: Conn_02x05_Odd_Even; PinHeader_2x05_P2.54mm_Vertical

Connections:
/LED_PWM_OUT1: J1.3, J2.10
/LED_PWM_OUT2: J1.1, J2.8
/LED_PWM_OUT3: J1.2, J2.6
/LED_PWM_OUT4: J1.4, J2.4
/LED_PWM_OUT5: J1.6, J2.2
/UV_LED_DRIVER_MODULE/LED_CATHODE_OUT: D1.1 (K); also elsewhere on the board
/UV_PWM: J2.1, J2.3, J2.5, J2.7, J2.9; also elsewhere on the board
GNDS: J1.12, J1.13, J1.14, J1.15, J1.16; also elsewhere on the board
VPP: D1.2 (A), J1.7, J1.8, J1.9, J1.10, J1.11; also elsewhere on the board

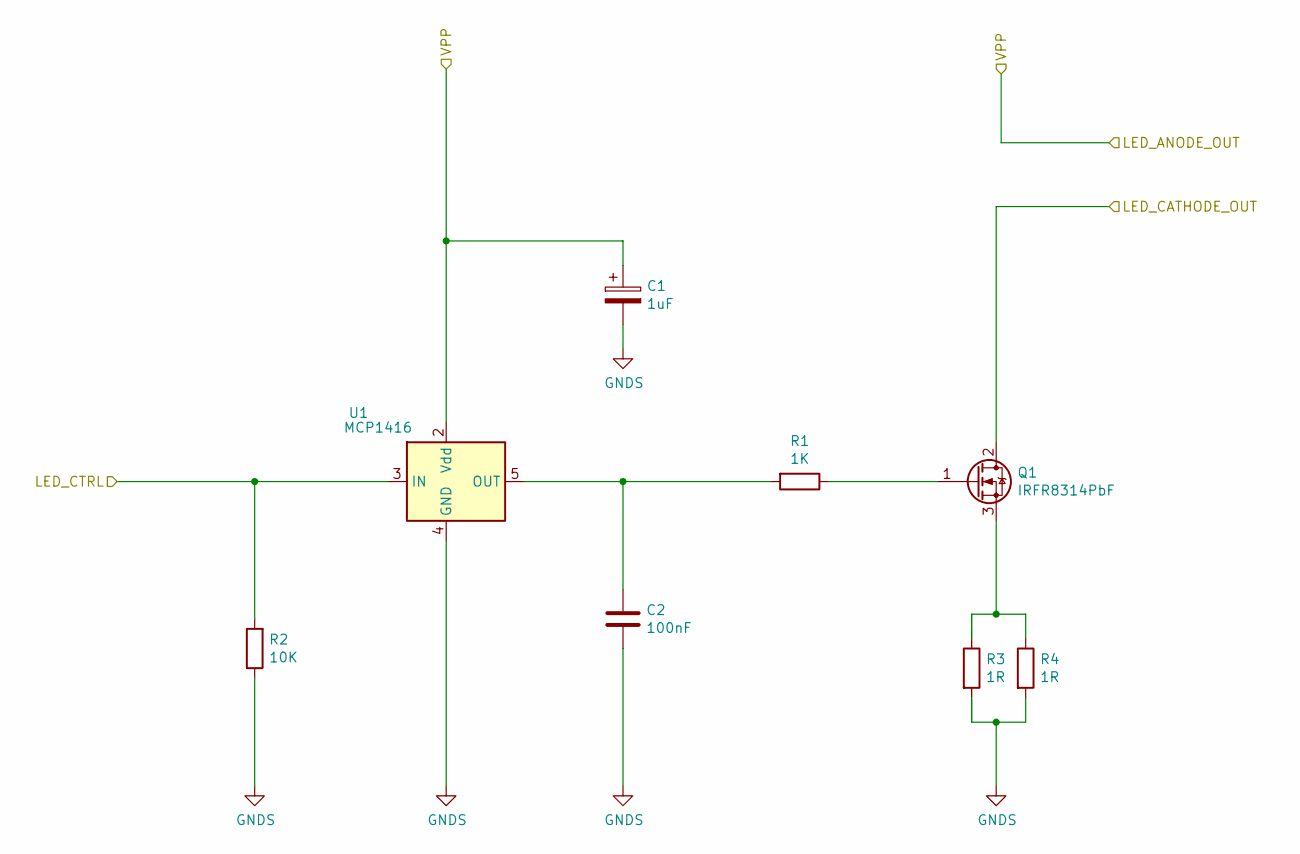
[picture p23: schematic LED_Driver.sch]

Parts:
C1: 1uF; C_1206_3216Metric_Pad1.42x1.75mm_HandSolder
C2: 100nF; C_1206_3216Metric_Pad1.42x1.75mm_HandSolder
Q1: IRFR8314PbF; TO-252-3_TabPin2
R1: 1K; R_1206_3216Metric_Pad1.42x1.75mm_HandSolder
R3, R4: 1R; R_1206_3216Metric_Pad1.42x1.75mm_HandSolder
R15: 10K; R_1206_3216Metric_Pad1.42x1.75mm_HandSolder
U1: MCP1416; SOT-23-5

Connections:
/UV_LED_DRIVER_MODULE/LED_CATHODE_OUT: Q1.2 (D); also elsewhere on the board
/UV_PWM: U1.3 (IN); also elsewhere on the board
GNDS: C1.2, C2.2, R3.2, R4.2, U1.4 (GND); also elsewhere on the board
unnamed: C2.1, R1.2, U1.5 (OUT)
unnamed: Q1.1 (G), R1.1
unnamed: Q1.3 (S), R3.1, R4.1
VPP: C1.1, U1.2 (Vdd); also elsewhere on the board

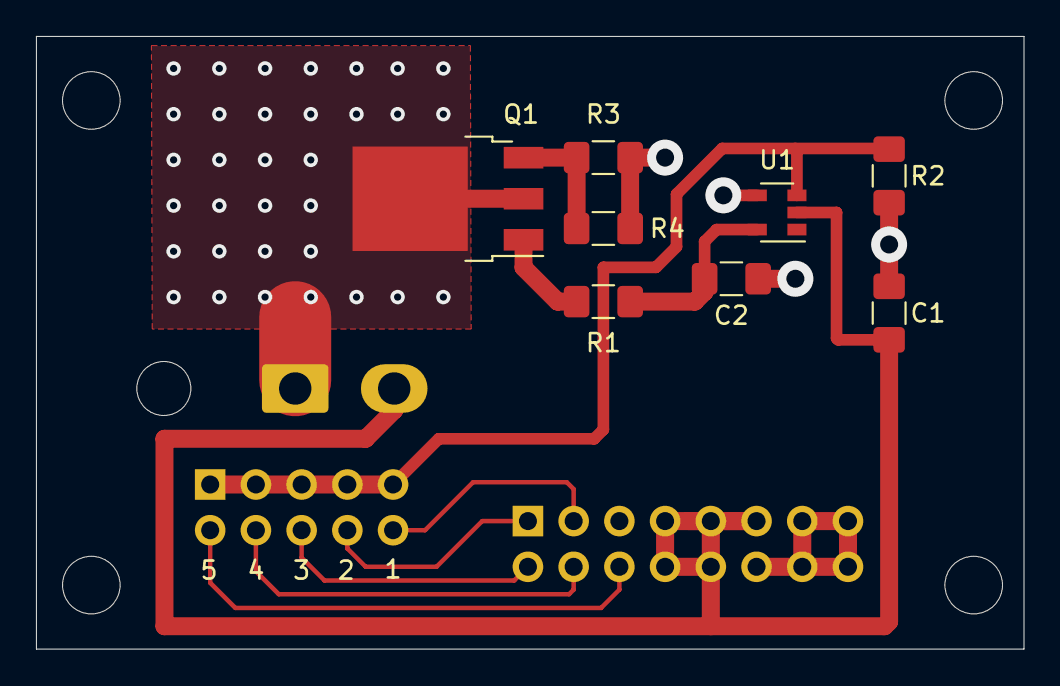
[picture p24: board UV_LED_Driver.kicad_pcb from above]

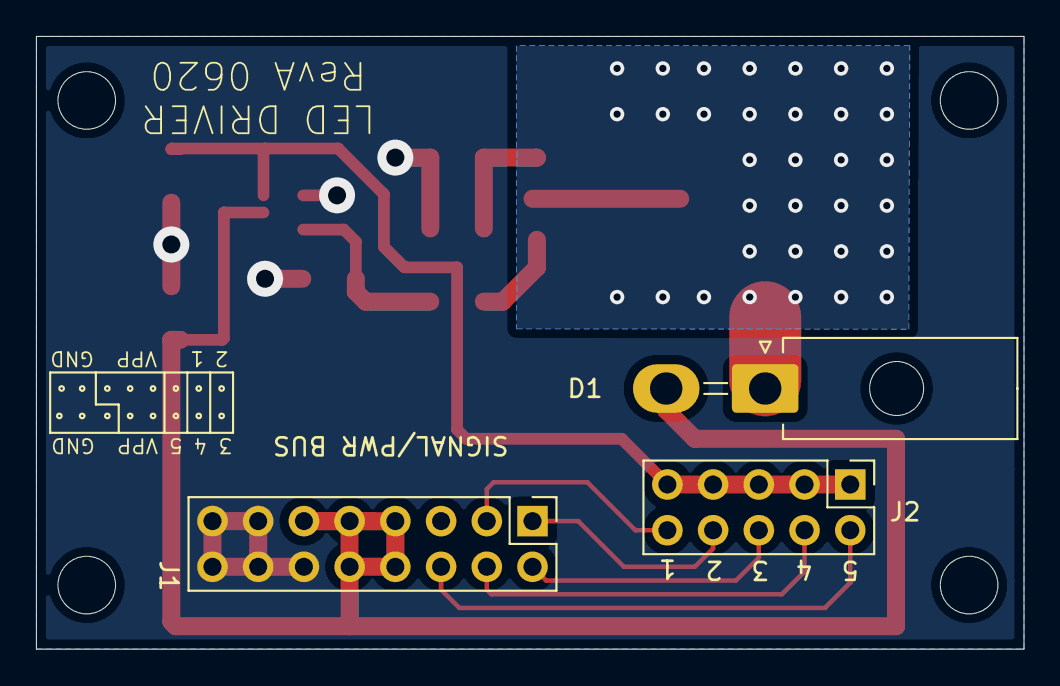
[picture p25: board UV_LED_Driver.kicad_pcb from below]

Board: 2 copper layers, 54.9 x 34.0 mm, 11 parts (3 on the bottom side), 12 nets.

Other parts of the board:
R2: 10K; R_1206_3216Metric_Pad1.42x1.75mm_HandSolder

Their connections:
/UV_PWM: R2.2; also elsewhere on the board
GNDS: R2.1; also elsewhere on the board

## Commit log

2020-04-25 Created Modular designs
    Combined project reuses modular design schematics
    - UV_LED_Driver_Modular/Driver/LED_Driver.sch
    - UV_LED_Driver_Modular/Controller/LED_Controller.sch
    [Controller.kicad_pcb, Controller.sch, LED_Controller.sch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]
2020-04-26 Changed TO225 NPN (MJE340) to SOT223 NPN (PZT2222A)
    [Controller.sch, LED_Controller.sch, LED_Driver.sch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]
2020-04-26 changed controller module LDO from SOT23 to SOT223
    [Controller.kicad_pcb, LED_Controller.sch]
2020-04-29 added IRS4427 mosfet gate driver to controller design
    [Controller.sch, LED_Controller.sch]
2020-05-09 docs update
    [39301020.stp, Controller.kicad_pcb, Controller.sch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]
2020-06-16 hw update
    modified output pin header
    [Controller.sch, UV_LED_Driver.kicad_pcb, UV_LED_Driver.sch]
2020-06-21 HW Updates
    ReRouted 5V to TFT VCC and LED pins.
    [Controller.kicad_pcb, Controller.sch, LED_Controller.sch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]
2020-06-24 hw update
    controller revb
    [Controller.kicad_pcb, LED_Controller.sch]
2020-06-27 modified headers
    [61201621621_Download_STP_61201621621_rev1.stp, Controller.kicad_pcb]
2020-06-27 Updated prototype designs for fab
    updated readme
    [Controller-B_Cu.gbr, Controller-B_Mask.gbr, Controller-B_SilkS.gbr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]
2020-07-06 added pull down resistor to MCU to prevent buzzer from sounding at boot
    [Controller.kicad_pcb, LED_Controller.sch]
2020-08-23 Added custom 100mm x 100mm LED panel
    [UVLED.sch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]

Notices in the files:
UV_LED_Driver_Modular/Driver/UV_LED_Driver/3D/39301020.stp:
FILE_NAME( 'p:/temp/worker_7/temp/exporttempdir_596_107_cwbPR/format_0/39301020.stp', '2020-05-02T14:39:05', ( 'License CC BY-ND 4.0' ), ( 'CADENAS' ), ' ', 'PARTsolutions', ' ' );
